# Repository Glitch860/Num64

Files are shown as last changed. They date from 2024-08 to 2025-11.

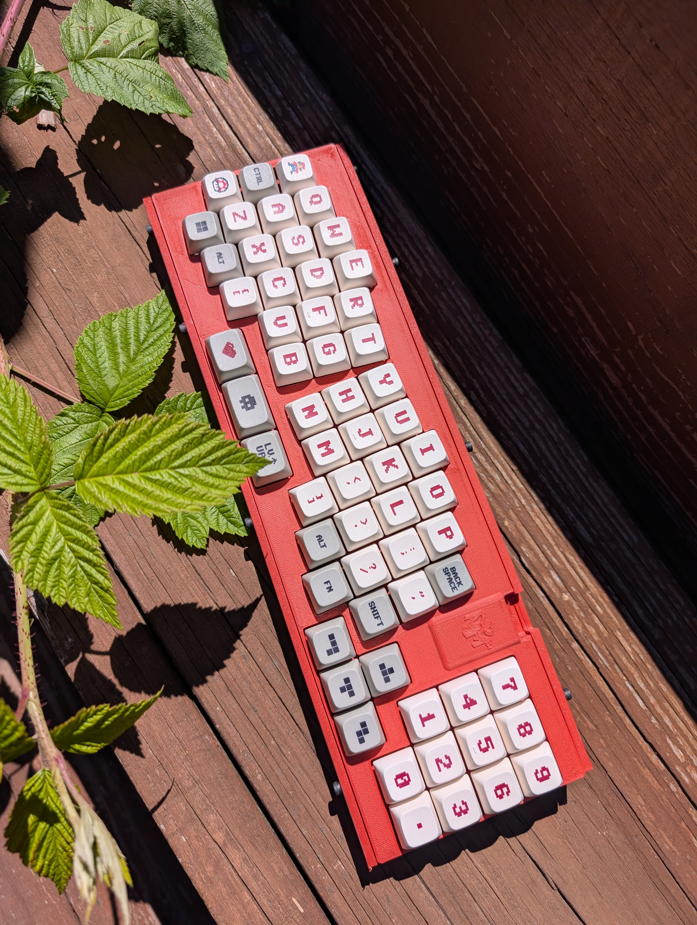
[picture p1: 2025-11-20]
images/Version1.jpg

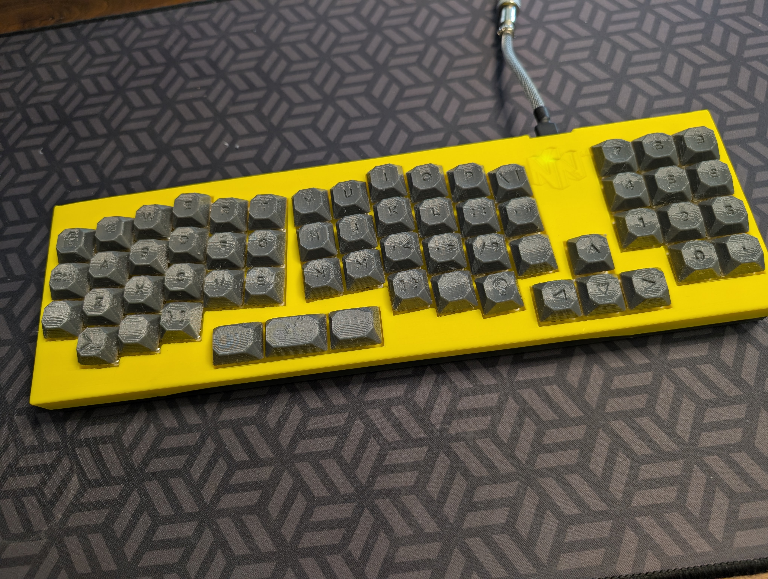
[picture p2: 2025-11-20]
images/Version2.jpg

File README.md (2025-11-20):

# Num64
Num64

3D printer files and Gerber files

STL files were printed on SOVOL SV06+ with a 300mmx300mmx340mm bed size. 

## Printer settings:
- .6mm nozzle
- layer height: .4mm
- first layer: .3mm
- infill: 20%

### V2 Printer Settings:
- .4mm Nozzle
- 3 Walls
- .2mm Layer height
- infill: 30%

hardware required:
- Nice!nano v2 controller or clone alernative
- M3x3x5 heat sink threaded insets
- M3x8 hex bolts
- [Battery](https://a.co/d/9JyL29i)
- *Optional* [JST 1.25mm 2 Pin connectors](https://a.co/d/bhRtTt9)
- *Optional* SMB power switch or [Battery helper](https://www.boardsource.xyz/products/Battery-Helper)
- 8x rubber feet

### V2 Case hardware required:
- 4x M2*20 screws
- 4x M2*12 screws
- 8X M2x4x3.2 Heat set inserts *possible to use M2 nuts instead*
- 6x Rubberfeet
- [Battery](https://a.co/d/9JyL29i)
- *Optional* [JST 1.25mm 2 Pin connectors](https://a.co/d/bhRtTt9)
- *Optional* SMB power switch or [Battery helper](https://www.boardsource.xyz/products/Battery-Helper)
- Nice!nano v2 controller or clone alernative

## Build Steps

1. Print the plate. *Recommended* use V2 Top Plate and V2 Base
2. While the plate is printing. Dend 60 diodes:



3. Solder diodes to PCB by putting them through the holes on the back side of the PCB. Bend the legs to help hold it in place. Make sure the black line of the diode is matching the silkscreen.



4. Clip the diode legs once they a soldered.
   >Be sure to save the diode legs for a later step.
   
5. *optional* Solder JST connector to controller. Red wire solder to + and black wire to -
      - *optional* Solder on a [Battery Helper](https://boardsource.xyz/products/battery-helper?_pos=1&_sid=83d434f6d&_ss=r) switch 
6. Solder hot swap controller sockets to the PDB, *recommended for height to clear the case*
7. Using the diode legs mount the controller in the hotswap sockets. Solder and clip the legs.
8. Flash the controller with [firmware](https://github.com/Glitch860/zmk-config-num64)
   - Under the master branch select Actions
   - Choose the latest successful workflow
   - Under the workflow artifacts download the firmware file
9. To flash the firmware use a pair of twizzers and touch the Gnd and Rst pins on the controller. You should see a drive call *NICENANO* show up.
    - Drag and drop the .uf2 file onto the mounted NiceNano drive
    - After a successful copy the drive will unmount and your keyboard should be working
    - *recommend* testing the PCB with an online keyboard tester. Using a pair of twizzers touch both holes of each switch.
10. Pop switches into the plate *60 in total needed*, be sure to firmly push the switch into each hole.
11. Align the plate with switches onto the PCB. Be sure no not to bend any of the switch legs. You will have to push the PCB and plate together to ensure the switch *CLICK* into place.


   
12. Solder all 60 switches to the PCB
  - :memo: Version 1 of the PCB **ONLY** supports 3 pin switches.



13. Strip a small piece of wire and solder it to D59. Connecting the two switches at the bottom.
   >⚠️This wire was missed in the design process for version 1. This should be corrected in newer releases on this Repo.



14. Print the case. View the STLs to determine which version you like best. 
15. Place the battery in the cutout.
16. connect the battery using the JST connector. OR solder directly to the controller
17. Using the M3x8 bolts screw the front and back to the plate
18. Put some little rubber feet on the bottom of the case.
19. Enjoy your new keyboard.

# License

</a></p>

You are free to:

Share — copy and redistribute the material in any medium or format

Adapt — remix, transform, and build upon the material

The licensor cannot revoke these freedoms as long as you follow the license terms.
Under the following terms:

Attribution — You must give appropriate credit, provide a link to the license, and indicate if changes were made. You may do so in any reasonable manner, but not in any way that suggests the licensor endorses you or your use.

NonCommercial — You may not use the material for commercial purposes.

ShareAlike — If you remix, transform, or build upon the material, you must distribute your contributions under the same license as the original.

No additional restrictions — You may not apply legal terms or technological measures that legally restrict others from doing anything the license permits.

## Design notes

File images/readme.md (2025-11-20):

# Image reference for Case designs

Each provides unique looks.

## Version 1

This version shows off the PCB. This is a lower profile case.
Version1

## Version 2

This version design is more like most keyboards. The idea was to mimic curves of the N64 console. 

Version2

### choose what case design works best for you!
> Recommended to print both cases on a larger form printer size 300mm+

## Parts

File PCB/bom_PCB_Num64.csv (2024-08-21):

Designator | Footprint | Quantity | Value | LCSC Part #
D1, D10, D11, D12, D13, D14, D15, D16, D17, D18, D19, D2, D20, D21, D22, D23, D24, D25, D26, D27, D28, D29, D3, D30, D31, D32, D33, D34, D35, D36, D37, D38, D39, D4, D40, D41, D42, D43, D44, D45, D46, D47, D48, D49, D5, D50, D51, D52, D53, D54, D55, D56, D57, D58, D59, D6, D60, D7, D8, D9 | D_DO-35_SOD27_P7.62mm_Horizontal | 60 | 1N4148
U1, U10, U11, U12, U13, U14, U15, U16, U17, U18, U19, U2, U20, U21, U22, U23, U24, U25, U26, U27, U28, U29, U3, U30, U31, U32, U33, U34, U35, U36, U37, U38, U39, U4, U40, U41, U42, U43, U44, U45, U46, U47, U48, U49, U5, U53, U54, U55, U56, U57, U58, U59, U6, U60, U7, U8, U9 | CherryMX_1.00u_LTST-A683CEGBW | 57 | CherryMX_LTST-A683CEGBW
U50, U52 | CherryMX_1.25u_LTST-A683CEGBW | 2 | CherryMX_LTST-A683CEGBW
U51 | CherryMX_1.50u_LTST-A683CEGBW | 1 | CherryMX_LTST-A683CEGBW
U61 | Nice_Nano_V2 | 1 | Nice_Nano_V2

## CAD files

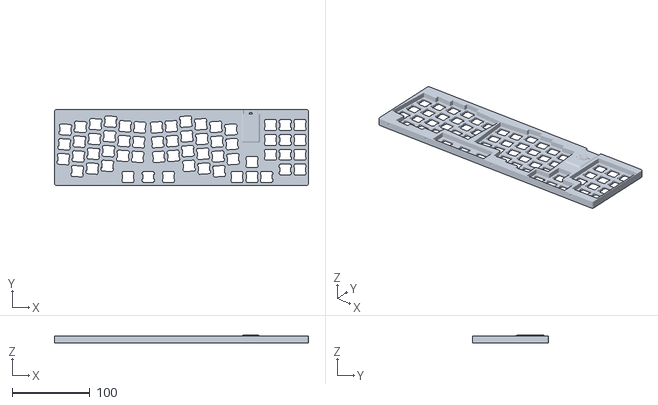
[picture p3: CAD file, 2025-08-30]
Num64V1_top.stl
326.7 x 97.6 x 10.7

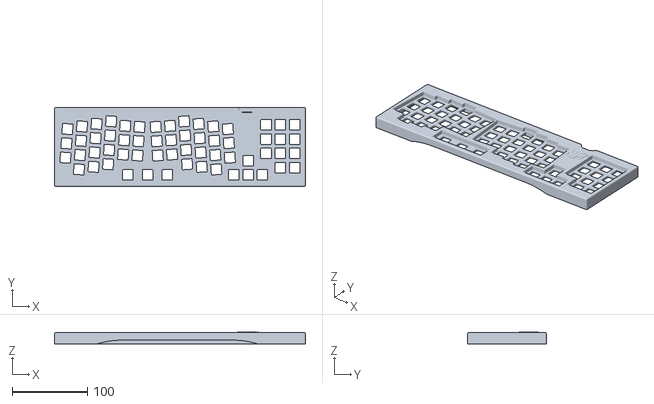
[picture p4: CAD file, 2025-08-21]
Num64_V2_TopPlate.stl
333.3 x 104.5 x 15.6

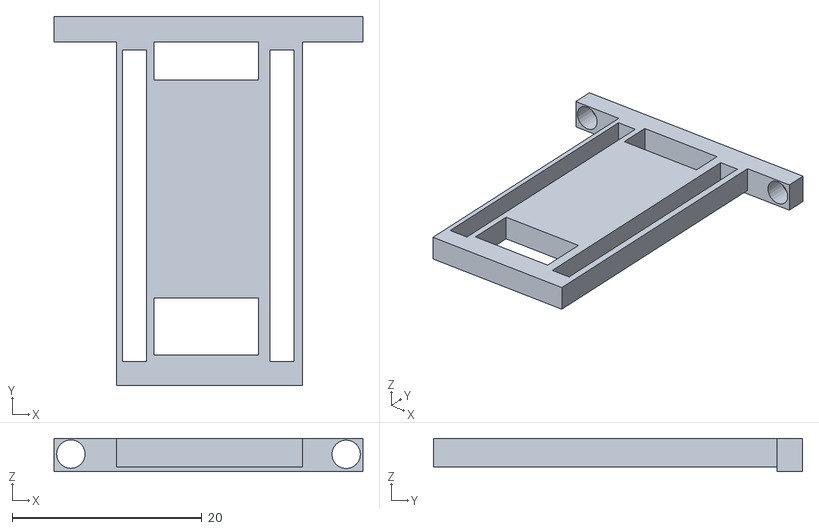
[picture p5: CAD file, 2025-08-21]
Controller_Carriage.stl
32.5 x 38.9 x 3.50

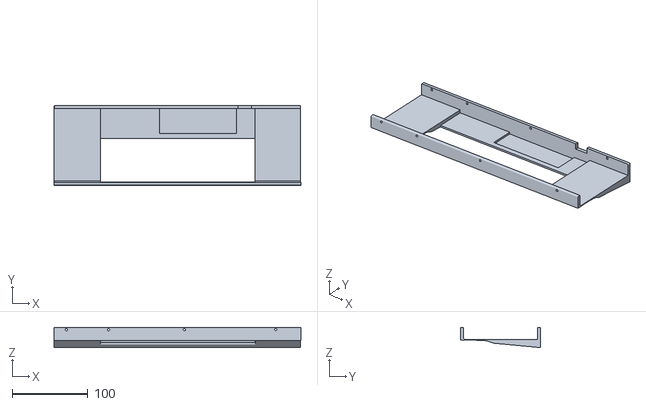
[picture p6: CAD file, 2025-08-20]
Num64v1_base.stl
326.7 x 106.3 x 26.8

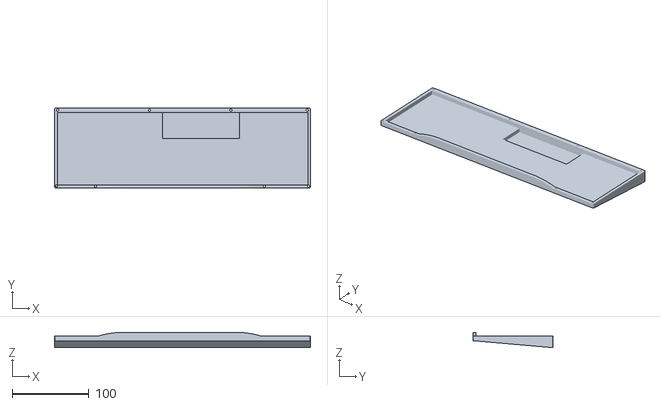
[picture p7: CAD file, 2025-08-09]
Num64_V2_Base.stl
333.3 x 104.5 x 20.0

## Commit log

2024-08-21 Add files via upload
    version 1 of the 3D printer file. Printed as one piece on a 300*300*340mm buildplate
    [Num64_V1.stl]
2024-08-28 Add files via upload
    Version 2. Final version of STLs for the case. USE THESE FILES
    [NUM64_plate.stl, Num64_Back.stl, Num64_Front.stl]
2024-09-05 Add files via upload
    latest versions with changes to the cut out for the controller to have better accessibility for USB. Back modified for battery cutout to allow for enough clearance.
    [NUM64_plate.stl, Num64_Back.stl, Num64_Front.stl]
2024-09-07 Add files via upload
    extruded minor adjustments to prevent printed gaps at .3mm quality
    [NUM64_plate.stl, Num64_Back.stl]
2024-10-29 Add files via upload
    version 1 of a all in one base. Printed with supports at an angle that fit on print bed. Depending on printer quality, nozzle size, and slicer settings results may vary.
    [Num64_Base.stl]
2025-08-09 Add files via upload
    Uploading STL Version 2 design of case.
    CHANGES:
    M2 screws and heat set inserts required. Total of 4x M2x20 and 4x Mx10 and 8 M2x4x3 heat inserts.
    [Num64_V2_Base.stl, Num64_V2_TopPlate.stl]
2025-08-09 Update README.md
    Updated Hardware requirements and recommendations for use V2 Case design
2025-08-17 Add files via upload
    Updated to include better cutout for various USB connectors to fit to controller better.
    [Num64_V2_TopPlate.stl]
2025-08-20 Delete NUM64_plate.stl
    Removing to add new changed STLs
    [NUM64_plate.stl]
2025-08-20 Delete Num64_Back.stl
    Removing to add new update STLs
    [Num64_Back.stl]
2025-08-20 Delete Num64_Front.stl
    Removing to add updated new STLs
    [Num64_Front.stl]
2025-08-20 Add files via upload
    Added new details. Cover over the controller and new embossed logo.
    [Num64V1_top.stl]
2025-08-20 Delete Num64_Base.stl
    Removing to add updated name of file
    [Num64_Base.stl]
2025-08-20 Add files via upload
    Updated with new logo
    [Num64_V2_TopPlate.stl]
2025-08-20 Update README.md
    Removed mention of LEDs
2025-08-21 Add files via upload
    Created for V2 Case ONLY. This allows for possible handwired builds
    [Controller_Carage.stl]
2025-08-21 Add files via upload
    Added Controller Carriage to allow for handwired build. No PCB required. This works ONLY with the V2 version of the case.
    [Controller_Carriage.stl]
2025-08-21 Add files via upload
    Updated too allow for handwired controller carriage
    [Num64_V2_TopPlate.stl]
2025-08-29 Add files via upload
    Updated clearance spacing for keycaps
    [Num64V1_top.stl]
2025-11-20 Add files via upload
    added photos of updated V1 and V2 case versions.

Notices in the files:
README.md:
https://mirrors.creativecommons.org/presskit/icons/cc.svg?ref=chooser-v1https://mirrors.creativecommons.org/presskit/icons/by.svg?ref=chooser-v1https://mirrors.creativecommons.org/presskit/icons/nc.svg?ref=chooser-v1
